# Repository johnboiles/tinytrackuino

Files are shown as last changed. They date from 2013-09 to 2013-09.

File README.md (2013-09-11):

Tiny Trackuino
==============
http://github.com/johnboiles/tinytrackuino

Small [Trackuino](http://www.trackuino.org/)-compatible board for transmitting APRS packets over 2m amateur radio.

Tiny Trackuino Front
Tiny Trackuino Back

Firmware
--------
The firmware is available at [github.com/johnboiles/trackuino](http://github.com/johnboiles/trackuino). It is modified from the [original Trackuino firmware](https://code.google.com/p/trackuino/) in order to support the newer 32u4 processors.

Bill of Materials
-----------------
2x [Screw Terminals 3.5mm Pitch (2-Pin)](https://www.sparkfun.com/products/8084)

1x [Screw Terminals 3.5mm Pitch (3-Pin)](https://www.sparkfun.com/products/8235)

1x [Arduino Pro Micro](https://www.sparkfun.com/products/11098)

1x [Female Headers](https://www.sparkfun.com/products/115)

1x [Break Away Headers](https://www.sparkfun.com/products/116)

1x [SMA Female Thru Hole Connector](https://www.sparkfun.com/products/593)

1x [EM406 (JST-SH) Horizontal Connector](https://www.sparkfun.com/products/10210)

1x [5V GPS with JST-SH connector](https://www.sparkfun.com/products/11571)

1x [JST-SH Cable](https://www.sparkfun.com/products/9123)

1x [Thru-hole Button](https://www.sparkfun.com/products/97)

1x [Radiometrix HX1 Transmitter](http://www.radiometrix.com/content/hx1)

2x [LM60 Temperature Sensor](http://www.digikey.com/scripts/DKSearch/dksus.dll?Detail&itemSeq=136296865&uq=635144426529530060)

2x [SOT23 N-Channel Mosfet](http://www.digikey.com/scripts/DKSearch/dksus.dll?Detail&itemSeq=136296519&uq=635144426529530060)

1x 10k Resistor 0603

1x 3.3k Resistor 0603

1x 1k Resistor 0603

2x 10uF Capacitor 1206

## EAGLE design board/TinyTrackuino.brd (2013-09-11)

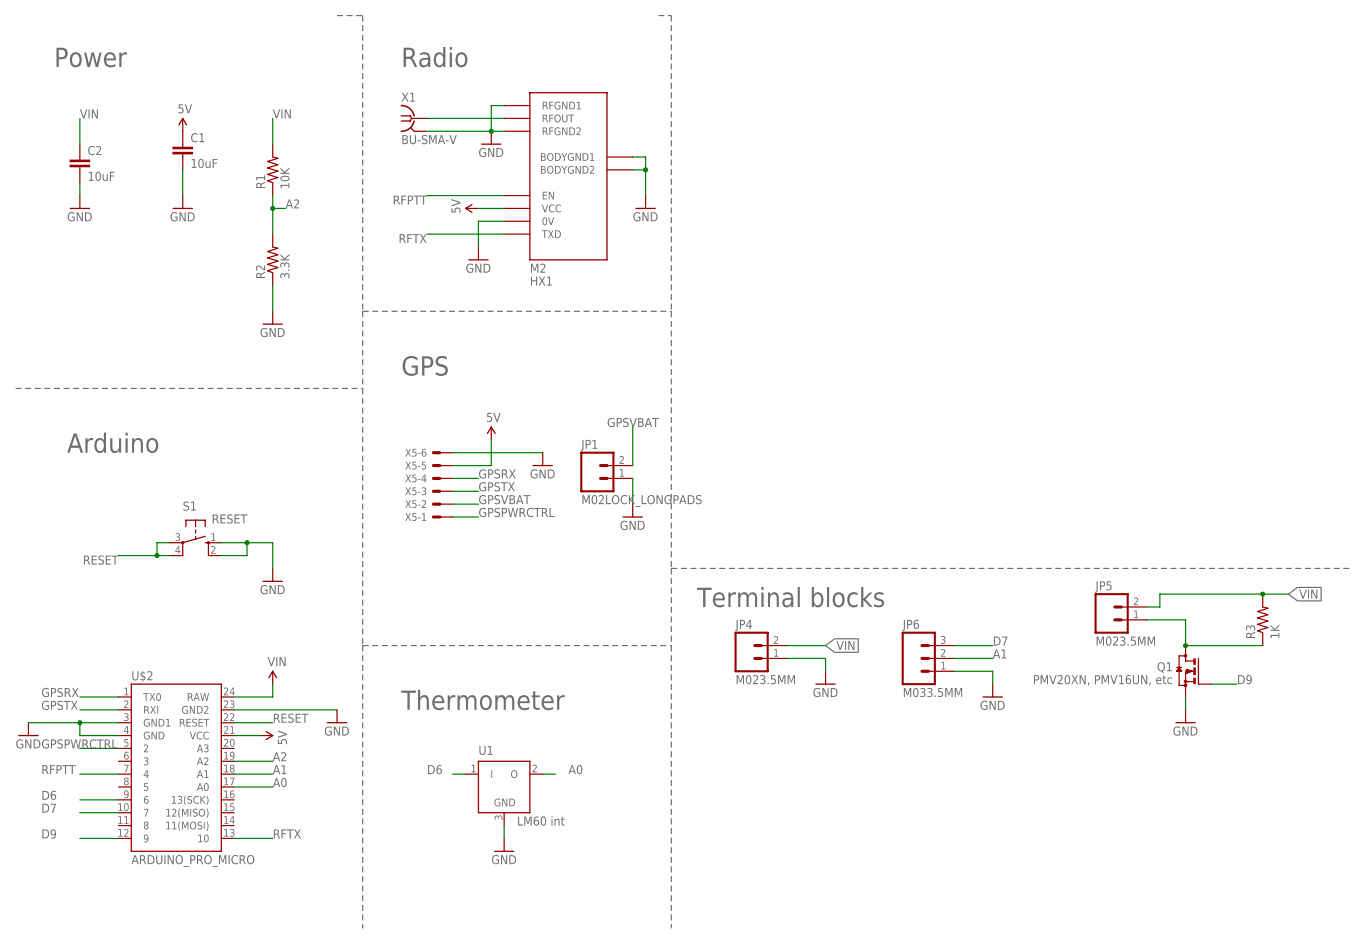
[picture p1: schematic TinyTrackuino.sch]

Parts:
C1, C2: 10uF; 1206
JP1: M02LOCK_LONGPADS; 1X02_LOCK_LONGPADS
JP4, JP5: M023.5MM; SCREWTERMINAL-3.5MM-2
JP6: M033.5MM; SCREWTERMINAL-3.5MM-3
M2: HX1
Q1: PMV20XN, PMV16UN, etc; SOT23
R1: 10K; 0603-RES
R2: 3.3K; 0603-RES
R3: 1K; 0603-RES
S1: RESET; B3F-10XX
U1: LM60 int; TO92
U$2: ARDUINO_PRO_MICRO
X1: BU-SMA-V
X5: SM06B-SRSS-TB

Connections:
5V: C1.1, M2.VCC, U$2.21 (VCC), X5.5
A0: U1.2 (O), U$2.17 (A0)
A1: JP6.2, U$2.18 (A1)
A2: R1.1, R2.2, U$2.19 (A2)
D6: U1.1 (I), U$2.9 (6)
D7: JP6.3, U$2.10 (7)
D9: Q1.1 (G), U$2.12 (9)
GND: C1.2, C2.2, JP1.1, JP4.1, JP6.1, M2.0V, M2.BODYGND1, M2.BODYGND2, M2.RFGND1, M2.RFGND2, Q1.2 (S), R2.1, S1.1 (S), S1.2 (S1), U1.3 (GND), U$2.3 (GND1), U$2.4 (GND), U$2.23 (GND2), X1.2 (GND), X1.3 (GND), X1.4 (GND), X1.5 (GND), X5.6
GPSPWRCTRL: U$2.5 (2), X5.1
GPSRX: U$2.1 (TX0), X5.4
GPSTX: U$2.2 (RXI), X5.3
GPSVBAT: JP1.2, X5.2
unnamed: JP5.1, Q1.3 (D), R3.1
RESET: S1.3, S1.4 (P1), U$2.22 (RESET)
RFOUT: M2.RFOUT, X1.1
RFPTT: M2.EN, U$2.7 (4)
RFTX: M2.TXD, U$2.13 (10)
VIN: C2.1, JP4.2, JP5.2, R1.2, R3.2, U$2.24 (RAW)

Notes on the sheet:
Power
Arduino
Radio
GPS
Thermometer
Terminal blocks

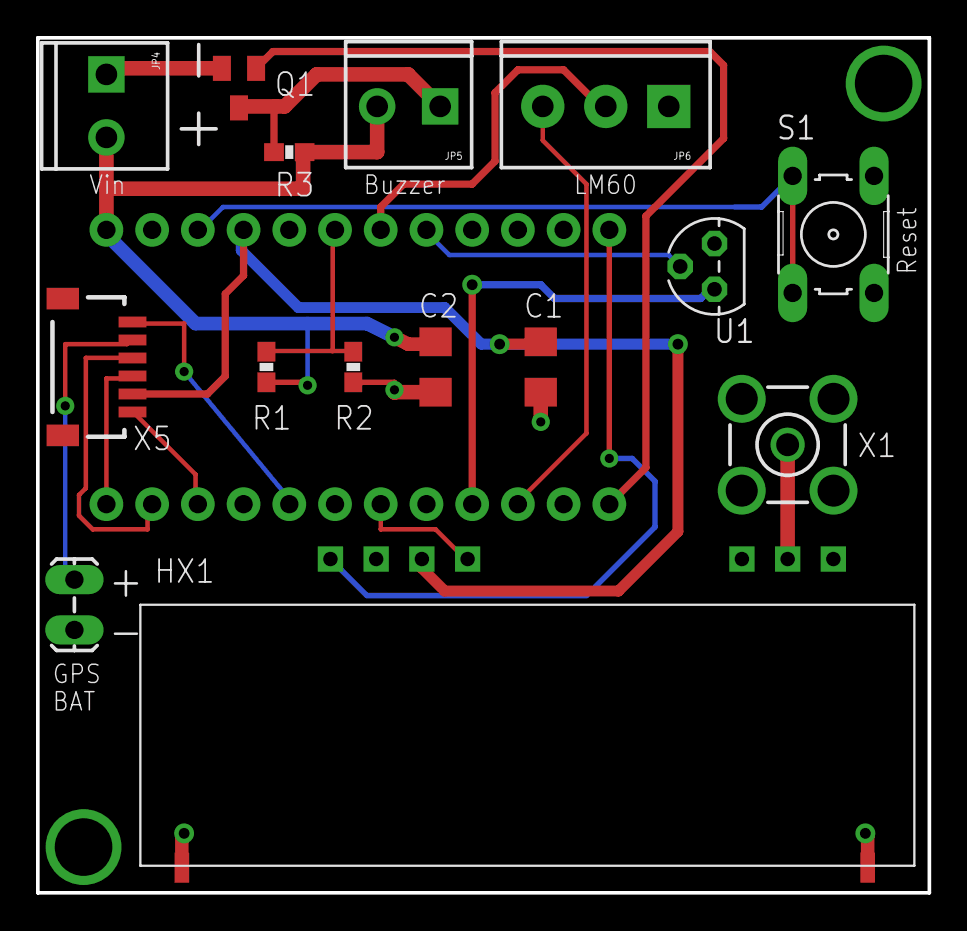
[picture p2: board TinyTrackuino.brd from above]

Board: 2 copper layers, 49.5 x 47.5 mm, 16 parts (0 on the bottom side), 18 nets.

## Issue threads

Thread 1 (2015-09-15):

SOT23 N-Channel Mosfet

Calimerorulez, 2015-09-15:
Hi John,

Looking at the BoM, it says "SOT23 N-Channel Mosfet". The link to Digikey is dead, sadly.

Could you tell me the part number of the component?

Thanks!

Calimerorulez, 2017-07-02:
Anyone?

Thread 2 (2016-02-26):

GPS EM-406

juanvivo, 2016-02-26:
Canwe  use a economic GPS as em-406? This GPS will have problems with height in moments of maximum height? A greeting and thanks for the information!

johnboiles, 2016-03-09:
I don't see why not, as long as you adapt it to work with a 5V supply / logic.

johnboiles, 2016-03-09:
You should also check out @KF7FER's version of [trackuino](https://github.com/KF7FER/trackuino/blob/master/trackuino/gps.cpp). He's got some cool code in there to automagically program ublox based chips for the correct altitude mode

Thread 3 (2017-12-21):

BoM to Schematic

mrtinvan, 2017-12-21:
Question about the BoM to Schematic. It looks like something is missing to me:

C1 / C2 - 10uF Cap - What voltage rating?
R1 - 10 kOhm (Digikey - 311-10KGRCT-ND)
R2 - 3.3 kOhm (Digikey - 311-3.3KGRCT-ND)
R3- 1kOhm (Digikey - 311-1.0KGRCT-ND)
Q1 - SOT-23 N Channel Mosfet - Any Details, BoM calls for 2x but only Q1 on the board?
LM60 - Any specifics other than a Thru Hole mount LM60?

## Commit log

2013-08-29 Fixing temp sensor silkscreen and gps connector
    [TinyTrackuino.brd, TinyTrackuino.sch]
2013-09-04 Almost final revision of board
    [TinyTrackuino.brd, TinyTrackuino.sch]
2013-09-07 Possibly final commit for revision 1
    [TinyTrackuino.brd, TinyTrackuino.sch]
2013-09-11 Using 3.5mm screw terminals instead of 5mm
    [TinyTrackuino.brd, TinyTrackuino.sch]
2013-09-11 Moving Vin to edge of board
    [TinyTrackuino.brd, TinyTrackuino.sch]

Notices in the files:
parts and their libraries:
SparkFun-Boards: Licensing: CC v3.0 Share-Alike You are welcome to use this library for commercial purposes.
